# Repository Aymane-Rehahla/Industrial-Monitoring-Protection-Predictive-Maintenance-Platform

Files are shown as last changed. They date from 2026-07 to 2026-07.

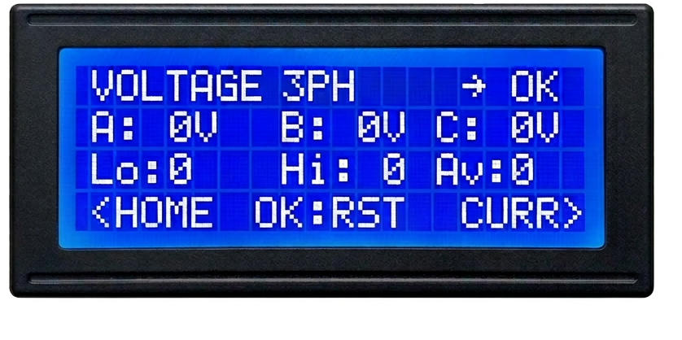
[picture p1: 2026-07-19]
hardware/photos/1775516696009-1775510813756-019d64b0-1b47-77af-adbd-3cf535df64a5.png

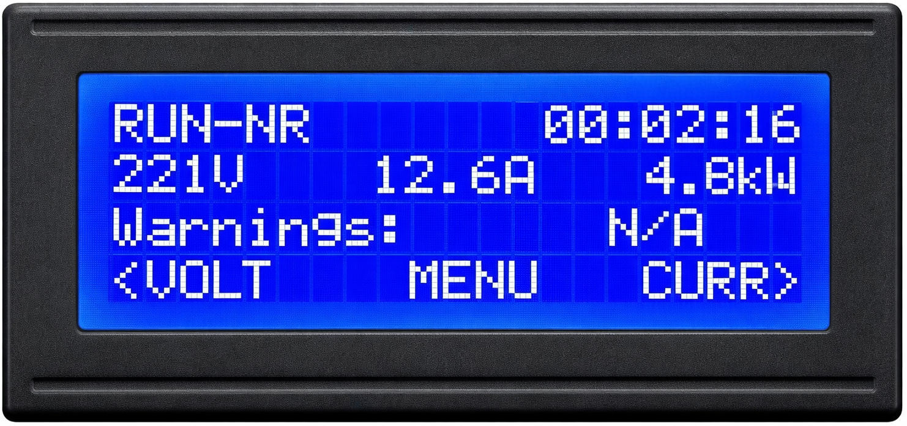
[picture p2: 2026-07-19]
hardware/photos/1775517319582-019d6513-c431-7847-a200-a261fa3e38d0.png

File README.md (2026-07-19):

# Industrial Distributed Monitoring & Protection Platform

> A modular industrial monitoring and protection system built with ESP32-S3 and ESP32 using ESP-IDF.
>
> Designed for reliability, fault tolerance, and safety-critical industrial environments.

---

## Overview

This project is my graduation project and represents the largest embedded system I have designed.

The system monitors industrial electrical and environmental parameters in real time while protecting equipment through a layered safety architecture.

Unlike many academic projects, this system was designed with **industrial reliability** as the primary goal.

It combines:

- Dual ESP32 architecture
- Independent hardware watchdogs
- Redundant communication
- Modular sensor framework
- Industrial HMI
- Remote monitoring dashboard
- Real-time protection algorithms

---

# Architecture

```
                   iPad Dashboard
                  (Web Application)
                         │
                    WiFi / TCP
                         │
                 ESP32 HMI Gateway
                         │
                  Encrypted ESP-NOW
                         │
      ┌──────────────────┴──────────────────┐
      │                                     │
 ESP32-S3 Safety Node A           ESP32-S3 Safety Node B
      │                                     │
      └────────── Cross Validation ─────────┘
                     │
              Dual ATtiny85 Watchdogs
                     │
               Independent NE555 Watchdog
                     │
               Industrial Safety Relay
```

---

# Key Features

## Industrial Protection

- Three-phase voltage monitoring
- Three-phase current monitoring
- Temperature monitoring
- Humidity monitoring
- Gas detection
- RPM monitoring
- Vibration monitoring
- Relay feedback verification
- Fault logging
- Alarm management

---

## Real-Time Processing

The ESP32-S3 performs all protection-critical calculations:

- RMS calculation
- Phase sequence detection
- Phase loss detection
- Voltage imbalance
- Current imbalance
- Frequency measurement
- Locked rotor detection
- Thermal I²t model
- Shock detection
- Safety trips

The ADC hardware provides roughly 860 samples/second in total — not per phase. Reconstructing an accurate current waveform for all three phases at once meant that budget had to be shared rather than used sequentially: the sample rate is divided across the three phases so each one is still captured within the same electrical cycle, instead of measuring one phase fully before moving to the next and introducing timing skew between them.

If a condition can damage equipment...

**the ESP32 reacts immediately.**

---

## Remote Monitoring

The ESP32 Gateway serves a web application accessible from an iPad or any browser.

Features include

- Live dashboard
- Real-time sensor values
- Alarm history
- Historical trends
- Waveform visualization
- Configuration interface
- Maintenance analytics

---

# Safety Philosophy

The most important design goal was **eliminating single points of failure.**

Every protection layer assumes another layer may eventually fail.

## Layer 1 — Software

Industrial state machines

Fault handling

CRC validation

Communication verification

Configuration validation

---

## Layer 2 — Dual ESP32 Supervision

Two ESP32 controllers continuously supervise each other.

Each verifies

- communication integrity
- sensor validity
- heartbeat
- operating state

If disagreement occurs

the system enters a safe state.

---

## Layer 3 — Intelligent Hardware Watchdogs

Two ATtiny85 microcontrollers independently supervise the ESP32 controllers.

Instead of accepting a simple heartbeat,

the watchdog expects a **rolling authentication key**.

This prevents situations where a crashed processor repeatedly outputs the same pulse.

If the rolling key becomes invalid,

the watchdog assumes the firmware is malfunctioning and removes the safety relay.

---

## Layer 4 — Independent NE555 Emergency Watchdog

Even watchdogs can fail.

To eliminate this possibility, an entirely independent NE555 hardware watchdog was added.

Unlike the programmable watchdogs,

the NE555 requires no firmware.

If every controller becomes unresponsive and no valid heartbeat reaches the timer,

the NE555 automatically

- opens the safety contactor
- resets the processors
- forces the system into a safe state

This final layer is completely hardware-based and cannot be affected by firmware bugs.

---

# Contactor State Verification

Commanding the contactor to open is not the same as confirming it actually did.

Under fault current, contactor contacts can weld or stick closed — silently defeating every protection layer above while still reporting a "safe" command was issued.

To catch this, voltage and current are sensed independently on both sides of the contactor: three points upstream (supply side) and three points downstream (load side), one per phase. Comparing the two sides directly reveals the real physical state of the contactor — whether it failed to open when commanded, or is welded shut — rather than relying on the command signal alone.

---

# Modular Sensor Architecture

One design objective was allowing industrial installations to evolve without modifying firmware.

Sensors are treated as independent modules.

Each module can

- be added
- removed
- enabled
- disabled
- configured

independently.

Protection limits are configurable rather than hardcoded.

A hardware switch also selects between simple (3-phase, no neutral) and complex (3-phase + neutral) wiring configurations, so the same platform can be installed across different machine and service types without a firmware change.

This allows the same firmware to support multiple industrial installations with different requirements.

---

# Communication

## ESP-NOW

- encrypted transport
- CRC validation
- packet sequencing
- custom protocol
- low latency

---

## Gateway

The ESP32 gateway converts embedded telemetry into data suitable for the web dashboard.

---

# Technologies

- ESP-IDF
- C
- FreeRTOS
- ESP32-S3
- ESP32
- ESP-NOW
- TCP/IP
- HTML
- JavaScript
- I2C
- UART
- SPI
- ADS1115
- SHT45
- ATtiny85

---

# Project Highlights

✔ Custom communication protocol

✔ Distributed embedded architecture

✔ Modular driver framework

✔ Industrial HMI

✔ Browser-based dashboard

✔ Hardware redundancy

✔ Layered watchdog system

✔ Safety relay verification

✔ Real-time monitoring

✔ Fault logging

✔ Configurable protection system

---

# Current Status

The platform is fully operational and demonstrates

- embedded firmware
- hardware integration
- communication
- industrial HMI
- remote monitoring

Some advanced algorithms are still under active development as the project continues to evolve.

---

# Future Work

- Advanced predictive diagnostics
- PLC integration (Modbus TCP)
- CAN Bus support
- MQTT gateway
- Cloud analytics
- Machine learning maintenance assistant

---

# About Me

I'm an Industrial Electronics Engineer from Algeria passionate about

- Embedded Systems
- Firmware Development
- Industrial Automation
- Safety-Critical Software

I'm currently seeking Embedded Software, Firmware, Electronics and Industrial Automation opportunities with visa sponsorship.

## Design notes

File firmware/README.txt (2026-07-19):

Industrial Monitoring and Protection System

This folder contains the complete project resources including:
- Embedded system code (ESP32-S3)
- Monitoring application
- Documentation

Project Status:
The project is currently in the final optimization and testing phase.
All files will be uploaded in the coming days. (Before 13-4-2026)

Author:
Aymane Rehahla

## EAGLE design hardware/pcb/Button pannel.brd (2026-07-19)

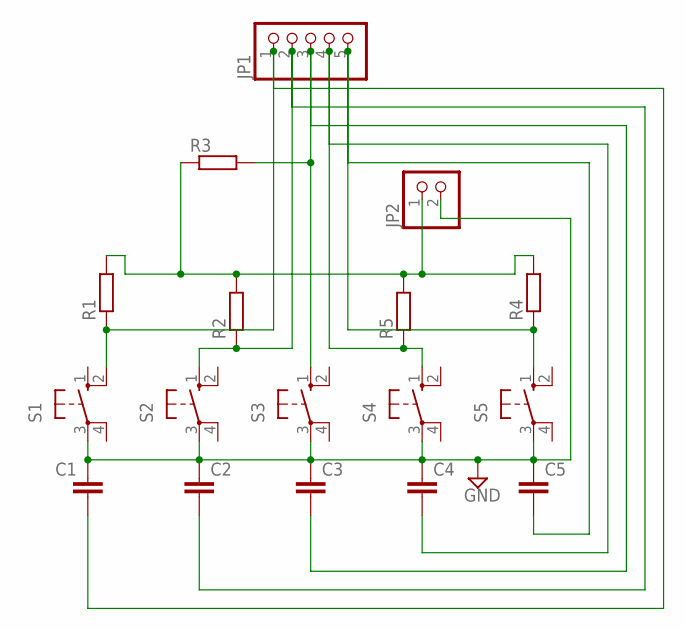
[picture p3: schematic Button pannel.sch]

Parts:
C1, C2, C3, C4, C5: C-EU025-025X050; C025-025X050
JP1: PINHD-1X5; 1X05
JP2: PINHD-1X2; 1X02
R1, R2, R3, R4, R5: R-EU_0204/7; 0204/7
S1, S2, S3, S4, S5: 40-XX; B3F-40XX

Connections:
GND: C1.1, C2.1, C3.1, C4.1, C5.1, JP2.2, S1.3, S2.3, S3.3, S4.3, S5.3
unnamed: C2.2, JP1.2, R2.1, S2.1 (S)
unnamed: C1.2, JP1.1, R1.1, S1.2 (S1)
unnamed: C3.2, JP1.3, R3.2, S3.1 (S)
unnamed: C4.2, JP1.4, R5.1, S4.1 (S)
unnamed: C5.2, JP1.5, R4.1, S5.1 (S)
unnamed: JP2.1, R1.2, R2.2, R3.1, R4.2, R5.2

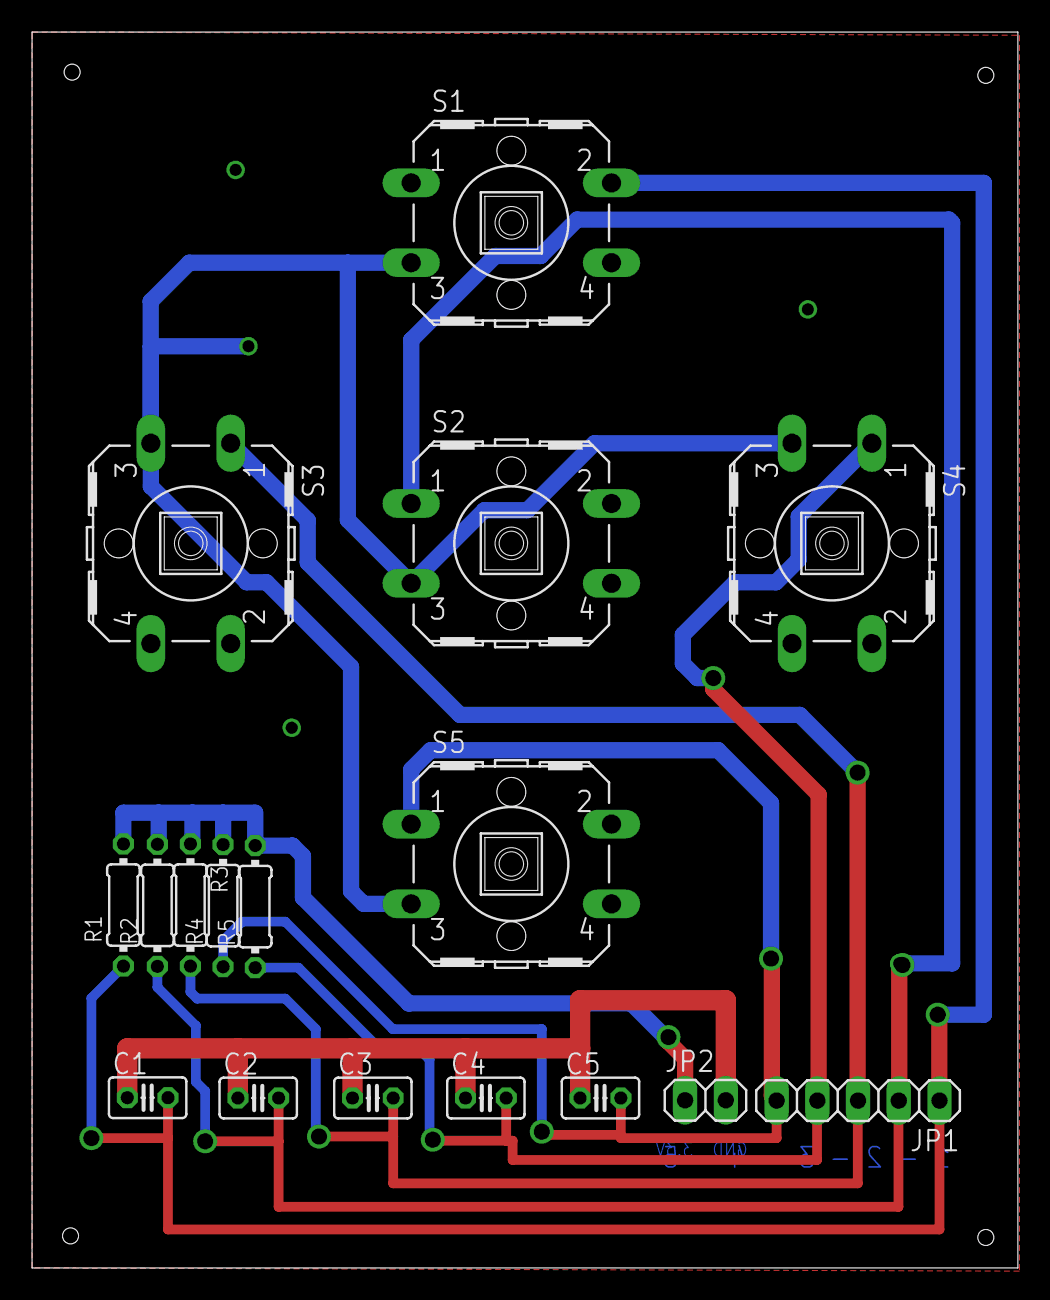
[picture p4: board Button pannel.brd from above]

Board: 2 copper layers, 61.5 x 77.1 mm, 17 parts (0 on the bottom side), 7 nets.

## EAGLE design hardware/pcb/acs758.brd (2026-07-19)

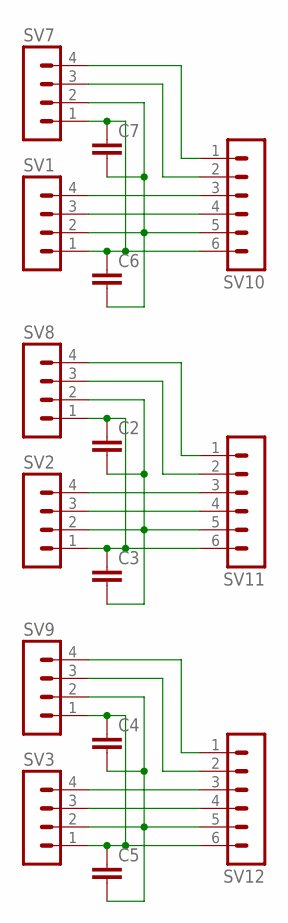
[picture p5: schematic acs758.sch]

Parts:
C2, C3, C4, C5, C6, C7: C-EU025-025X050; C025-025X050
SV1, SV2, SV3, SV7, SV8, SV9: MA04-1
SV10, SV11, SV12: MA06-1

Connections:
unnamed: SV1.3, SV10.4
unnamed: C4.1, C5.1, SV3.1, SV9.1, SV12.6
unnamed: SV2.3, SV11.4
unnamed: SV3.3, SV12.4
unnamed: SV3.4, SV12.3
unnamed: SV9.3, SV12.2
unnamed: SV9.4, SV12.1
unnamed: C2.1, C3.1, SV2.1, SV8.1, SV11.6
unnamed: SV2.4, SV11.3
unnamed: SV8.3, SV11.2
unnamed: SV8.4, SV11.1
unnamed: C6.1, C7.1, SV1.1, SV7.1, SV10.6
unnamed: SV1.4, SV10.3
unnamed: C6.2, C7.2, SV1.2, SV7.2, SV10.5
unnamed: C2.2, C3.2, SV2.2, SV8.2, SV11.5
unnamed: SV7.3, SV10.2
unnamed: SV7.4, SV10.1
unnamed: C4.2, C5.2, SV3.2, SV9.2, SV12.5

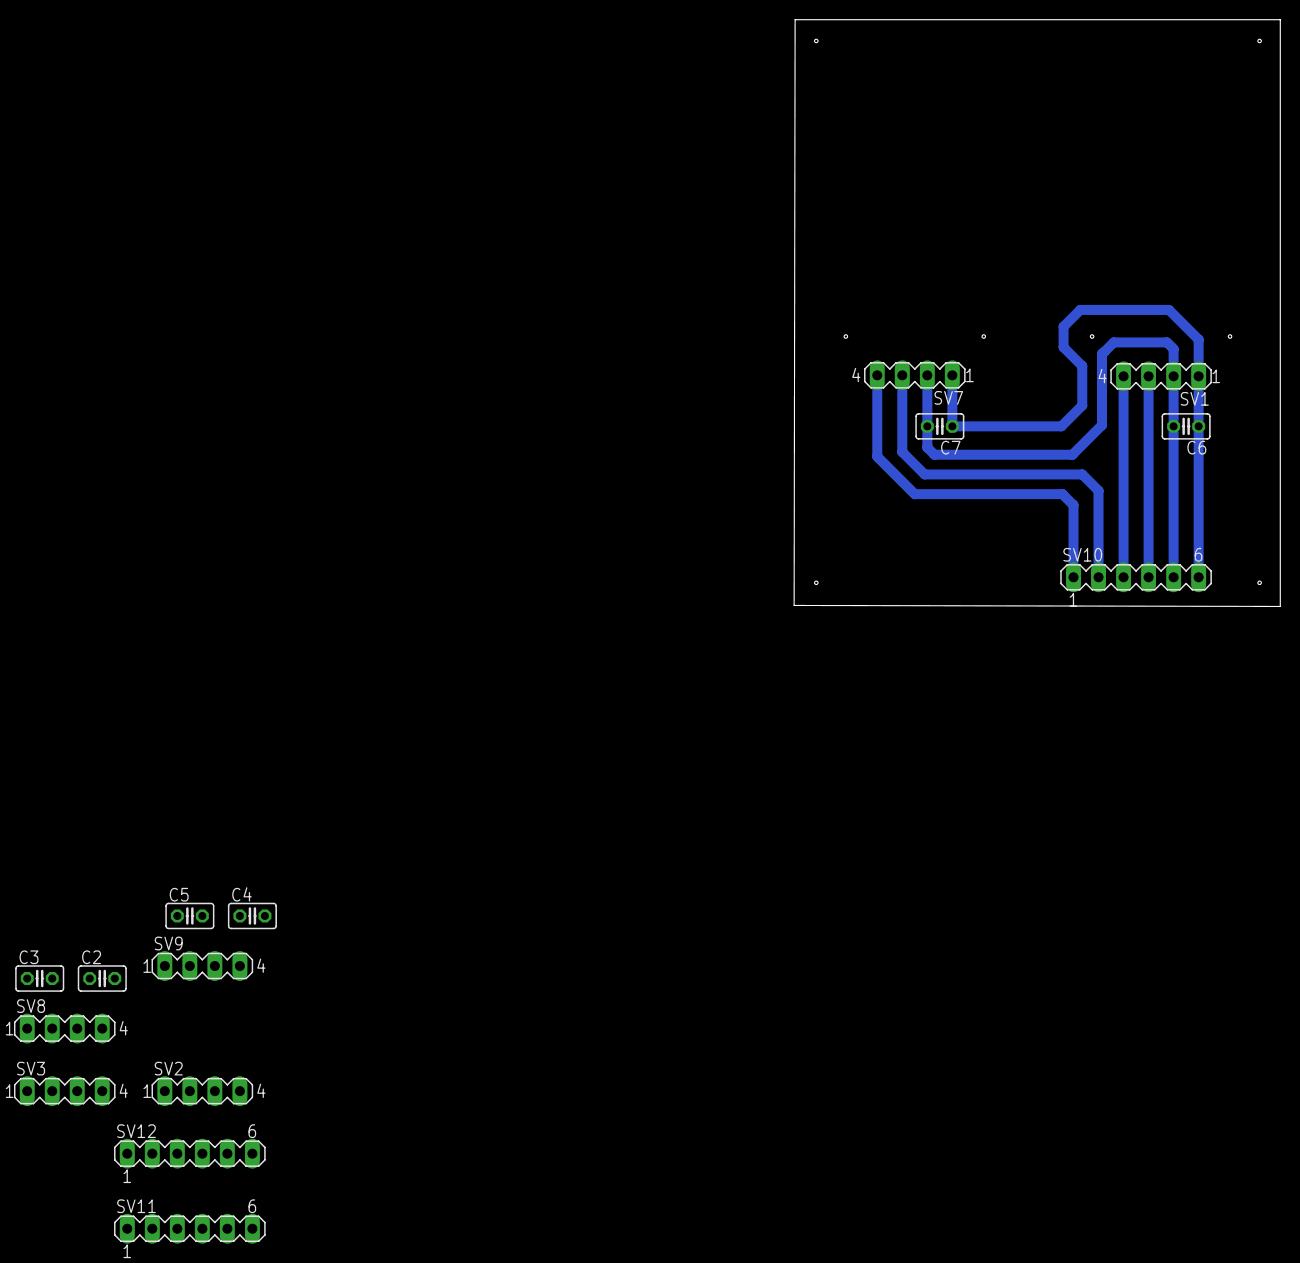
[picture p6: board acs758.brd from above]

Board: 2 copper layers, 49.3 x 59.6 mm, 15 parts (0 on the bottom side), 18 nets.

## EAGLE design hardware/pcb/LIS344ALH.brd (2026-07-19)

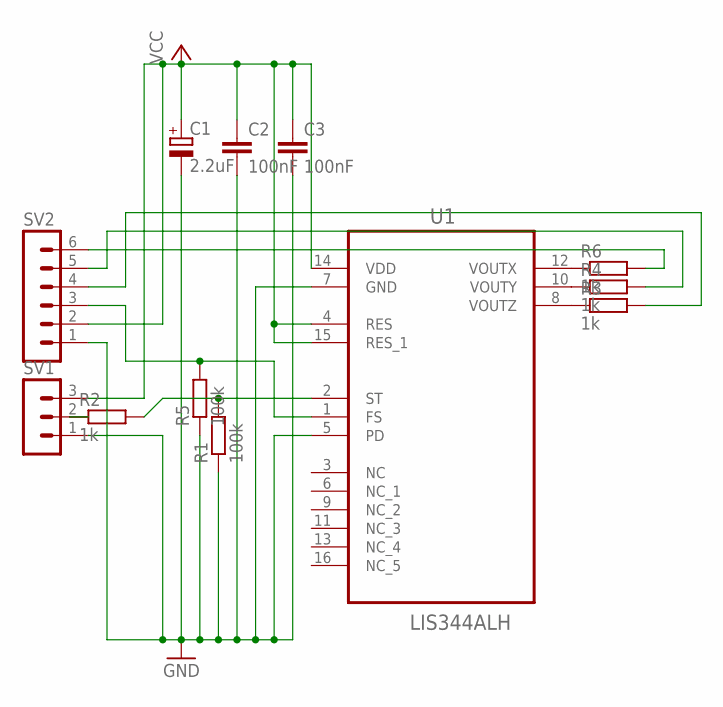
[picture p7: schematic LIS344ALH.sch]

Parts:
C1: 2.2uF; E2,5-6E
C2, C3: 100nF; C2.5-2
R1, R5: 100k; 0204/7
R2, R3, R4, R6: 1k; 0204/7
SV1: MA03-1
SV2: MA06-1
U1: LIS344ALH; LGA16R65P4X4_400X400X160

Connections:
GND: C1.-, C2.2, C3.2, R1.1, R5.1, SV1.1, SV2.1, U1.5 (PD), U1.7 (GND)
unnamed: R6.1, U1.12 (VOUTX)
unnamed: R4.1, U1.10 (VOUTY)
unnamed: R3.1, U1.8 (VOUTZ)
unnamed: R6.2, SV2.6
unnamed: R4.2, SV2.5
unnamed: R3.2, SV2.4
unnamed: R2.1, SV1.2
unnamed: R1.2, R2.2, U1.2 (ST)
unnamed: R5.2, SV2.3, U1.1 (FS)
VCC: C1.+, C2.1, C3.1, SV1.3, SV2.2, U1.4 (RES), U1.14 (VDD), U1.15 (RES_1)

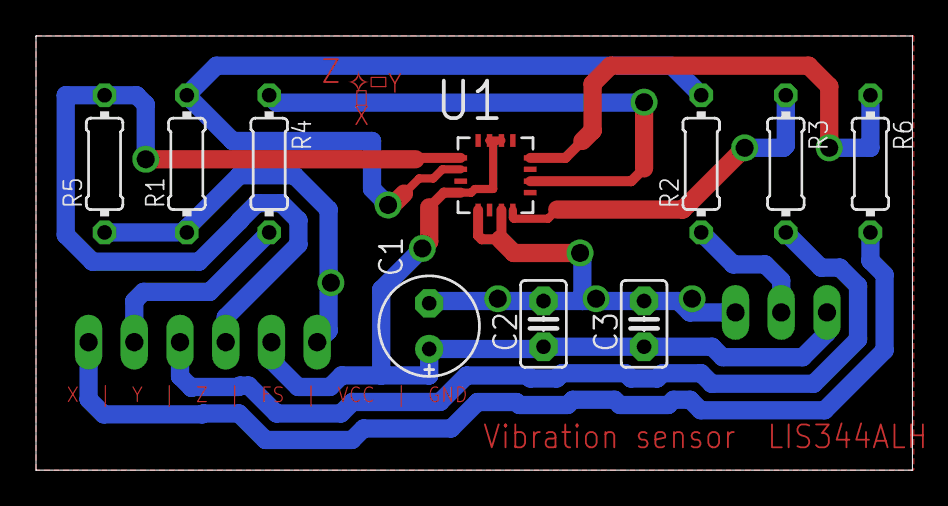
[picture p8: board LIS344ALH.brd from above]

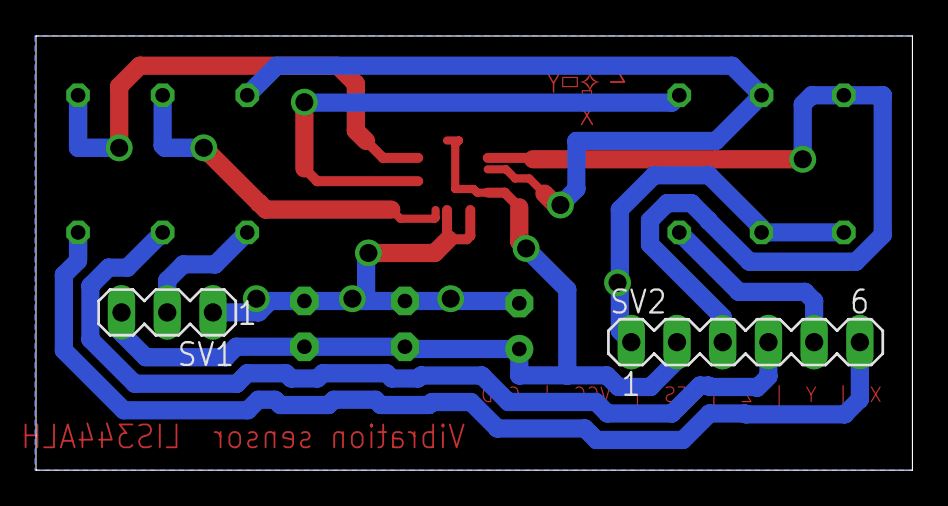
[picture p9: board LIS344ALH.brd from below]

Board: 2 copper layers, 48.7 x 24.1 mm, 12 parts (2 on the bottom side), 11 nets.

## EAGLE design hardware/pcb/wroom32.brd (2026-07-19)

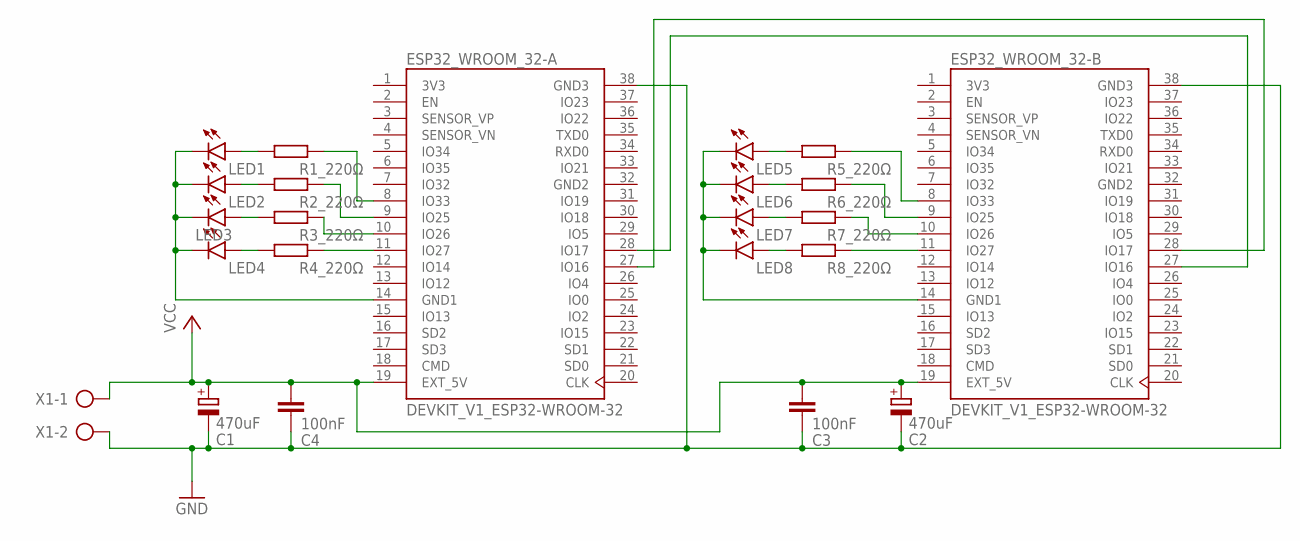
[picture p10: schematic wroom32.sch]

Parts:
C1, C2: 470uF; E2,5-7
C3, C4: 100nF; C025-024X044
ESP32_WROOM_32-A, ESP32_WROOM_32-B: DEVKIT_V1_ESP32-WROOM-32; MODULE_DEVKIT_V1_ESP32-WROOM-32
LED1, LED2, LED3, LED4, LED5, LED6, LED7, LED8: TLLG4400; LED3MM
R1_220Ω, R2_220Ω, R3_220Ω, R4_220Ω, R5_220Ω, R6_220Ω, R7_220Ω, R8_220Ω: R-EU_0207/10; 0207/10
X1: AK500/2-H

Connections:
3V3: ESP32_WROOM_32-A.1 (3V3), ESP32_WROOM_32-B.1 (3V3)
GND: C1.-, C2.-, C3.2, C4.2, ESP32_WROOM_32-A.38 (GND3), ESP32_WROOM_32-B.38 (GND3), X1.2
GND2: ESP32_WROOM_32-A.32 (GND2), ESP32_WROOM_32-B.32 (GND2)
unnamed: ESP32_WROOM_32-A.28 (IO17), ESP32_WROOM_32-B.27 (IO16)
unnamed: ESP32_WROOM_32-A.27 (IO16), ESP32_WROOM_32-B.28 (IO17)
unnamed: ESP32_WROOM_32-B.14 (GND1), LED5.K (C), LED6.K (C), LED7.K (C), LED8.K (C)
unnamed: ESP32_WROOM_32-A.14 (GND1), LED1.K (C), LED2.K (C), LED3.K (C), LED4.K (C)
unnamed: LED1.A, R1_220Ω.1
unnamed: LED2.A, R2_220Ω.1
unnamed: LED3.A, R3_220Ω.1
unnamed: LED4.A, R4_220Ω.1
unnamed: ESP32_WROOM_32-A.11 (IO27), R4_220Ω.2
unnamed: ESP32_WROOM_32-A.10 (IO26), R3_220Ω.2
unnamed: ESP32_WROOM_32-A.9 (IO25), R2_220Ω.2
unnamed: ESP32_WROOM_32-A.8 (IO33), R1_220Ω.2
unnamed: ESP32_WROOM_32-B.8 (IO33), R5_220Ω.2
unnamed: ESP32_WROOM_32-B.9 (IO25), R6_220Ω.2
unnamed: ESP32_WROOM_32-B.10 (IO26), R7_220Ω.2
unnamed: ESP32_WROOM_32-B.11 (IO27), R8_220Ω.2
unnamed: LED8.A, R8_220Ω.1
unnamed: LED7.A, R7_220Ω.1
unnamed: LED6.A, R6_220Ω.1
unnamed: LED5.A, R5_220Ω.1
VCC: C1.+, C2.+, C3.1, C4.1, ESP32_WROOM_32-A.19 (EXT_5V), ESP32_WROOM_32-B.19 (EXT_5V), X1.1

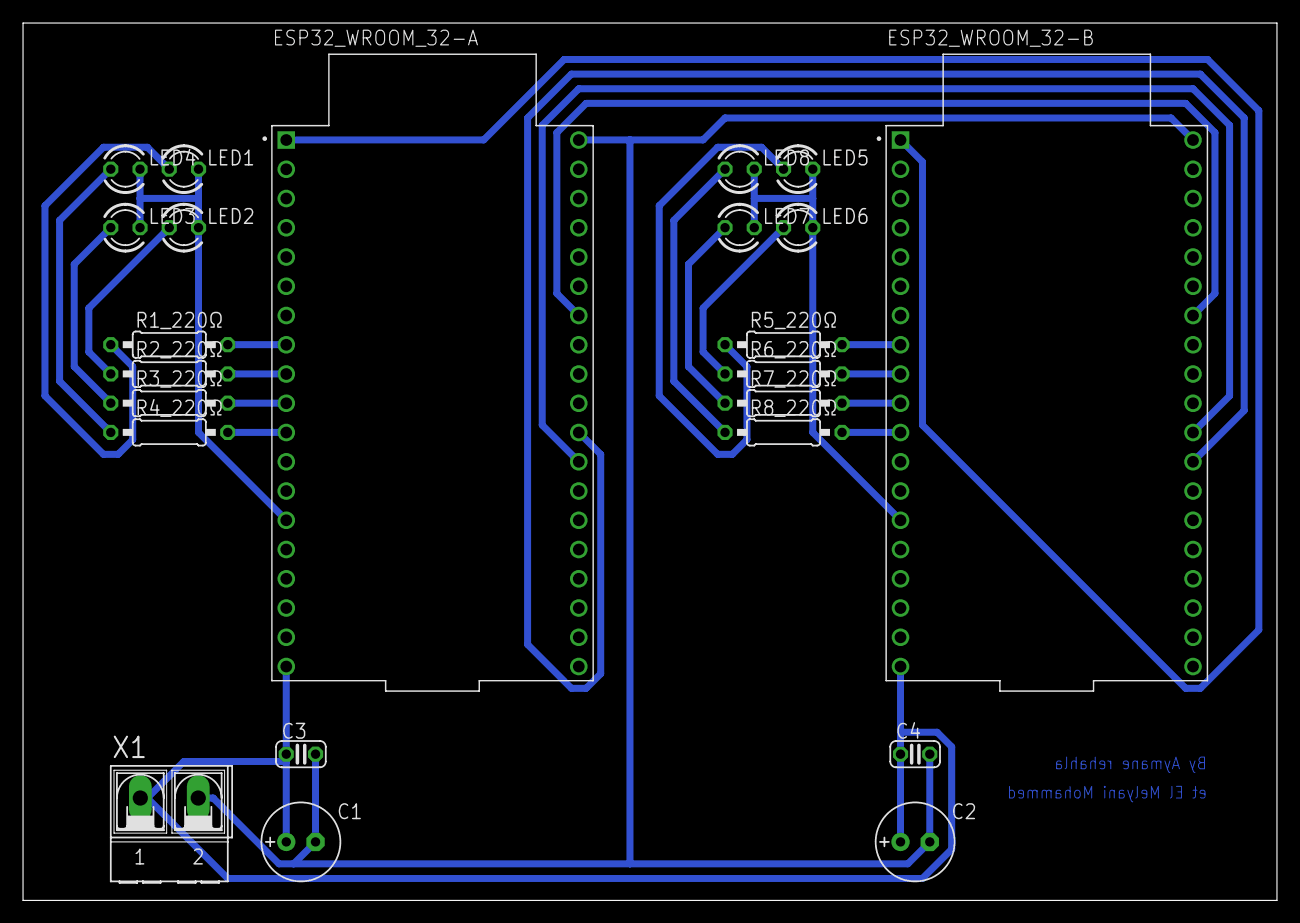
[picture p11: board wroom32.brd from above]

Board: 2 copper layers, 108.9 x 76.2 mm, 23 parts (0 on the bottom side), 24 nets.

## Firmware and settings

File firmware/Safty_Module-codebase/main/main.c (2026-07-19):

/**
 * @file    main.c
 * @brief   Production main — init all subsystems in dependency order.
 * @version 4.0.0
 *
 * CHANGELOG:
 *   4.0.0  2025-01-01  Added comm subsystem init (NVS, ESP-NOW, pairing, telemetry).
 *   3.0.0  2025-01-01  Removed GPIO 5 test task — moved to menu.
 *   2.0.0  2025-01-01  Added GPIO 5 test fault button.
 *   1.1.0  2025-01-01  Removed event-stealing debug loop.
 */

#include "freertos/FreeRTOS.h"
#include "freertos/task.h"
#include "esp_log.h"

#include "system_types.h"
#include "app_config.h"
#include "hal_gpio.h"
#include "hal_i2c.h"
#include "hal_adc.h"
#include "hal_uart.h"
#include "system_status.h"
#include "config_manager.h"
#include "measurement.h"
#include "protection.h"
#include "fault_handler.h"
#include "redundancy.h"
#include "sensor_manager.h"
#include "hmi_manager.h"
#include "drv_lcd2004.h"
#include "drv_buttons.h"
#include "drv_relay.h"
#include "nvs_config.h"
#include "espnow_link.h"
#include "pairing.h"
#include "telemetry.h"

static const char *TAG = "MAIN";

void app_main(void)
{
    error_code_t err;

    ESP_LOGI(TAG, "===== BOOT START =====");
    ESP_LOGI(TAG, "Firmware %s  Built %s %s",
             FIRMWARE_VERSION_STRING, FIRMWARE_BUILD_DATE,
             FIRMWARE_BUILD_TIME);

    /* ── Phase 1: HAL ── */
    hal_gpio_init();
    hal_i2c_init(I2C_BUS_SENSORS);
    hal_i2c_init(I2C_BUS_SHARED);

    err = drv_lcd2004_init();
    ESP_LOGI(TAG, "LCD init: %d  detected=%d", err,
             drv_lcd2004_is_detected());

    err = drv_relay_init();
    ESP_LOGI(TAG, "Relay init: %d", err);

    hal_adc_init();
    hal_uart_init();

    /* ── Phase 2: NVS (must precede WiFi and any NVS consumers) ── */
    err = nvs_config_init();
    ESP_LOGI(TAG, "NVS init: %d", err);

    /* ── Phase 3: Core modules ── */
    system_status_init();
    config_manager_init();
    measurement_init();
    protection_init();
    fault_handler_init();
    redundancy_init();
    sensor_manager_init();

    /* ── Phase 4: Communication (ESP-NOW → pairing → telemetry) ── */
    err = espnow_link_init();
    ESP_LOGI(TAG, "ESP-NOW init: %d", err);

    err = pairing_init();
    ESP_LOGI(TAG, "Pairing init: %d  peers=%u", err,
             pairing_get_peer_count());

    err = telemetry_init();
    ESP_LOGI(TAG, "Telemetry init: %d", err);

    if (err == ERR_OK) {
        telemetry_start();
        ESP_LOGI(TAG, "Telemetry started");
    }

    /* ── Phase 5: HMI (last — everything else must be ready) ── */
    err = hmi_manager_init();
    ESP_LOGI(TAG, "HMI init: %d", err);

    ESP_LOGI(TAG, "===== SYSTEM RUNNING =====");

    /* ── Supervisor loop — watchdog + diagnostics ── */
    while (1) {
        vTaskDelay(pdMS_TO_TICKS(5000));

        telemetry_stats_t tstat;
        telemetry_get_stats(&tstat);

        ESP_LOGI(TAG, "screen=%d role=%d state=%d faults=%lu "
                 "telem_fast=%lu slow=%lu peers=%u",
                 hmi_manager_get_current_screen(),
                 system_status_get_role(),
                 system_status_get_state(),
                 (unsigned long)fault_handler_get_total_count(),
                 (unsigned long)tstat.fast_packets_sent,
                 (unsigned long)tstat.slow_packets_sent,
                 pairing_get_peer_count());
    }
}

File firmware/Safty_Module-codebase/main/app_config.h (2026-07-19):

/**
 * @file    app_config.h
 * @brief   All hardware constants, pin definitions, timing, I2C addresses.
 *          Single point of truth for every configurable value.
 * @version 1.1.0
 * @date    2025-01-01
 * @safety  CRITICAL — Wrong pin or timing constant = damaged equipment.
 *
 * CHANGELOG:
 *   1.1.0  2025-01-01  Fixed duplicate defines, added missing HMI constants.
 *   1.0.0  2025-01-01  Initial release — frozen pin map.
 */

#ifndef APP_CONFIG_H
#define APP_CONFIG_H

#include <stdint.h>
#include <stdbool.h>

/* ═══════════════════════════════════════════════════════════════════════
 *  BOARD / FIRMWARE IDENTIFICATION
 * ═══════════════════════════════════════════════════════════════════════ */
#define FIRMWARE_VERSION_MAJOR   1
#define FIRMWARE_VERSION_MINOR   0
#define FIRMWARE_VERSION_PATCH   0
#define FIRMWARE_VERSION_STRING  "1.0.0"
#define FIRMWARE_BUILD_DATE      __DATE__
#define FIRMWARE_BUILD_TIME      __TIME__
#define BOARD_NAME               "ESP32-S3-N16R8"

/* ═══════════════════════════════════════════════════════════════════════
 *  I2C BUS 0 — SAFETY-CRITICAL SENSORS (ADS1115 x2)
 *  NEVER share this bus with user-facing devices.
 * ═══════════════════════════════════════════════════════════════════════ */
#define PIN_I2C_BUS0_SDA         8
#define PIN_I2C_BUS0_SCL         9
#define I2C_BUS0_FREQ_HZ        400000
#define I2C_BUS0_TIMEOUT_MS      100

/* ═══════════════════════════════════════════════════════════════════════
 *  I2C BUS 1 — SHARED (LCD + SHT45)
 * ═══════════════════════════════════════════════════════════════════════ */
#define PIN_I2C_BUS1_SDA         17
#define PIN_I2C_BUS1_SCL         18
#define I2C_BUS1_FREQ_HZ        100000
#define I2C_BUS1_TIMEOUT_MS      100

/* ═══════════════════════════════════════════════════════════════════════
 *  I2C DEVICE ADDRESSES
 * ═══════════════════════════════════════════════════════════════════════ */
#define I2C_ADDR_ADS1115_VOLTAGE 0x48
#define I2C_ADDR_ADS1115_CURRENT 0x49
#define I2C_ADDR_LCD2004         0x27
#define I2C_ADDR_LCD2004_ALT     0x3F
#define I2C_ADDR_SHT45           0x44

/* ═══════════════════════════════════════════════════════════════════════
 *  I2C SAFETY PARAMETERS
 * ═══════════════════════════════════════════════════════════════════════ */
#define I2C_RETRY_COUNT                  3
#define I2C_BUS_RECOVERY_CLOCK_PULSES   16
#define I2C_ERROR_THRESHOLD             10

/* ═══════════════════════════════════════════════════════════════════════
 *  ANALOG SENSOR PINS (ADC1 ONLY — ADC2 conflicts with WiFi/ESP-NOW)
 * ═══════════════════════════════════════════════════════════════════════ */
#define PIN_ADC_MQ2              1
#define PIN_ADC_MQ4              2
#define PIN_ADC_MQ9              4
#define PIN_ADC_LIS344_X         5
#define PIN_ADC_LIS344_Y         6
#define PIN_ADC_MAX9814          7

/* ═══════════════════════════════════════════════════════════════════════
 *  CD4053BE ANALOG MUX
 * ═══════════════════════════════════════════════════════════════════════ */
#define PIN_MUX_SELECT           3

/* ═══════════════════════════════════════════════════════════════════════
 *  DIGITAL SENSOR PINS
 * ═══════════════════════════════════════════════════════════════════════ */
#define PIN_HALL_RPM            41

/* ═══════════════════════════════════════════════════════════════════════
 *  BUTTON PINS — all active LOW with internal pull-up
 * ═══════════════════════════════════════════════════════════════════════ */
#define PIN_BTN_LEFT            10
#define PIN_BTN_RIGHT           11
#define PIN_BTN_UP              12
#define PIN_BTN_DOWN            21
#define PIN_BTN_OK              42

#define BTN_ACTIVE_LEVEL         0
#define BTN_DEBOUNCE_MS         50
#define BTN_LONG_PRESS_MS     2000
#define BTN_REPEAT_DELAY_MS    500
#define BTN_REPEAT_RATE_MS     150
#define BTN_SCAN_INTERVAL_MS    20      /* How often buttons are polled */

#define APP_BUTTON_COUNT         5

/* ═══════════════════════════════════════════════════════════════════════
 *  BUZZER — PWM via LEDC peripheral
 * ═══════════════════════════════════════════════════════════════════════ */
#define PIN_BUZZER              13

#define BUZZER_LEDC_TIMER        0
#define BUZZER_LEDC_CHANNEL      0
#define BUZZER_LEDC_SPEED_MODE   0
#define BUZZER_LEDC_RESOLUTION  10
#define BUZZER_DUTY_50_PERCENT 512
#define BUZZER_DEFAULT_DUTY    512      /* 50% duty for 10-bit resolution */

/* Tone frequencies (Hz) */
#define TONE_CLICK_HZ         4000
#define TONE_NAV_HZ           2500
#define TONE_CONFIRM_HZ       3000
#define TONE_WARNING_HZ       2000
#define TONE_ERROR_HZ         1000
#define TONE_ALARM_HZ          800
#define TONE_STARTUP_HZ       1500

/* Tone durations (ms) */
#define TONE_CLICK_MS           20
#define TONE_NAV_MS             50
#define TONE_CONFIRM_MS        100
#define TONE_WARNING_MS        200
#define TONE_ERROR_MS          400
#define TONE_ALARM_MS          500
#define TONE_STARTUP_MS        150
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

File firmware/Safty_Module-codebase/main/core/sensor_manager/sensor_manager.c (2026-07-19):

// ═══ FILE: main/core/sensor_manager/sensor_manager.c ═══
/**
 * @file    sensor_manager.c
 * @brief   Sensor manager — STUB implementation with default sensor registry.
 * @version 1.0.0
 * @date    2025-01-01
 * @safety  MEDIUM — Stub only; replace before production.
 *
 * CHANGELOG:
 *   1.0.0  2025-01-01  STUB release.
 */

#include "core/sensor_manager/sensor_manager.h"
#include "app_config.h"

#include "esp_log.h"

#include <string.h>

static const char *TAG = "sensor_manager";

#define NO_GPIO  0xFF
#define NO_I2C   0xFF

/* Justification: Sensor registry must persist across all calls.
 * Modified by add/remove/enable.  File scope. */
static sensor_entry_t s_registry[SENSOR_REGISTRY_MAX];
static uint32_t       s_count       = 0;
static bool           s_initialized = false;

/**
 * @brief  Add one entry to the registry during init.
 *
 * WHY a helper: The default sensor table has 15 entries.  Without
 * this helper, init() would exceed the 50-line limit.
 */
static void reg_add(sensor_type_t type, const char *name,
                    uint8_t gpio, uint8_t bus, uint8_t addr,
                    bool removable)
{
    if (s_count >= SENSOR_REGISTRY_MAX) { return; }

    sensor_entry_t *e = &s_registry[s_count];
    e->type        = type;
    strncpy(e->name, name, SENSOR_NAME_MAX_LEN - 1);
    e->name[SENSOR_NAME_MAX_LEN - 1] = '\0';
    e->gpio_pin    = gpio;
    e->i2c_bus     = bus;
    e->i2c_addr    = addr;
    e->is_enabled  = true;
    e->is_removable = removable;
    e->is_online   = true;  /* STUB: all online */
    s_count++;
}

/* STUB — returns fake data */
error_code_t sensor_manager_init(void)
{
    s_count = 0;

    /* Three-phase voltage via ADS1115 #1 on I2C Bus 0 */
    reg_add(SENSOR_VOLTAGE, "Voltage L1", NO_GPIO, 0, 0x48, false);
    reg_add(SENSOR_VOLTAGE, "Voltage L2", NO_GPIO, 0, 0x48, false);
    reg_add(SENSOR_VOLTAGE, "Voltage L3", NO_GPIO, 0, 0x48, false);

    /* Three-phase current via ADS1115 #2 on I2C Bus 0 */
    reg_add(SENSOR_CURRENT, "Current L1", NO_GPIO, 0, 0x49, false);
    reg_add(SENSOR_CURRENT, "Current L2", NO_GPIO, 0, 0x49, false);
    reg_add(SENSOR_CURRENT, "Current L3", NO_GPIO, 0, 0x49, false);

    /* Environmental sensors on I2C Bus 1 */
    reg_add(SENSOR_TEMP,     "Temperature", NO_GPIO, 1, 0x44, true);
    reg_add(SENSOR_HUMIDITY,  "Humidity",    NO_GPIO, 1, 0x44, true);

    /* Gas sensors via ADC */
    reg_add(SENSOR_GAS_SMOKE,   "MQ-2 Smoke",   1, NO_I2C, 0, true);
    reg_add(SENSOR_GAS_METHANE, "MQ-4 Methane",  2, NO_I2C, 0, true);
    reg_add(SENSOR_GAS_CO,      "MQ-9 CO",       4, NO_I2C, 0, true);

    /* Vibration via ADC */
    reg_add(SENSOR_VIBRATION, "Vibration X", 5, NO_I2C, 0, false);
    reg_add(SENSOR_VIBRATION, "Vibration Y", 6, NO_I2C, 0, false);

    /* Hall-effect RPM */
    reg_add(SENSOR_RPM, "RPM", 41, NO_I2C, 0, false);

    /* Audio level via ADC */
    reg_add(SENSOR_AUDIO, "Audio Level", 7, NO_I2C, 0, false);

    s_initialized = true;
    ESP_LOGW(TAG, "STUB: sensor_manager_init — %lu sensors registered",
             (unsigned long)s_count);
    return ERR_OK;
}

/* STUB — returns fake data */
error_code_t sensor_manager_get_sensor_count(uint32_t *count_out)
{
    if (count_out == NULL) { return ERR_NULL_POINTER; }
    *count_out = s_count;
    return ERR_OK;
}

/* STUB — returns fake data */
error_code_t sensor_manager_get_sensor(uint32_t index,
                                       sensor_entry_t *entry_out)
{
    if (entry_out == NULL) { return ERR_NULL_POINTER; }
    if (index >= s_count)  { return ERR_INVALID_ARG; }

    *entry_out = s_registry[index];
    return ERR_OK;
}

/* STUB — returns fake data */
error_code_t sensor_manager_find_by_type(sensor_type_t type,
                                         sensor_entry_t *entry_out)
{
    if (entry_out == NULL) { return ERR_NULL_POINTER; }

    for (uint32_t i = 0; i < s_count && i < SENSOR_REGISTRY_MAX; i++) {
        if (s_registry[i].type == type) {
            *entry_out = s_registry[i];
            return ERR_OK;
        }
    }
    return ERR_NOT_FOUND;
}

/* STUB — appends to registry */
error_code_t sensor_manager_add_sensor(const sensor_entry_t *entry)
{
    if (entry == NULL) { return ERR_NULL_POINTER; }
    if (s_count >= SENSOR_REGISTRY_MAX) { return ERR_BUFFER_FULL; }

    s_registry[s_count] = *entry;
    s_count++;
    ESP_LOGI(TAG, "STUB: sensor added — %s (total %lu)",
             entry->name, (unsigned long)s_count);
    return ERR_OK;
}

/* STUB — removes from registry */
error_code_t sensor_manager_remove_sensor(uint32_t index)
{
    if (index >= s_count) { return ERR_INVALID_ARG; }
    if (!s_registry[index].is_removable) { return ERR_INVALID_ARG; }

    /* Shift remaining entries down. Bounded by SENSOR_REGISTRY_MAX. */
    for (uint32_t i = index; i < s_count - 1 && i < SENSOR_REGISTRY_MAX - 1; i++) {
        s_registry[i] = s_registry[i + 1];
    }
    s_count--;
    return ERR_OK;
}

/* STUB */
error_code_t sensor_manager_enable_sensor(uint32_t index, bool enable)
{
    if (index >= s_count) { return ERR_INVALID_ARG; }
    s_registry[index].is_enabled = enable;
    return ERR_OK;
}

/* STUB — returns fake data */
bool sensor_manager_is_sensor_online(sensor_type_t type)
{
    for (uint32_t i = 0; i < s_count && i < SENSOR_REGISTRY_MAX; i++) {
        if (s_registry[i].type == type && s_registry[i].is_online) {
            return true;
        }
    }
    return false;
}

const char *sensor_manager_get_type_name(sensor_type_t type)
{
    switch (type) {
        case SENSOR_NONE:        return "None";
        case SENSOR_VOLTAGE:     return "Voltage";
        case SENSOR_CURRENT:     return "Current";
        case SENSOR_TEMP:        return "Temperature";
        case SENSOR_HUMIDITY:    return "Humidity";
        case SENSOR_GAS_SMOKE:   return "Gas (Smoke)";
        case SENSOR_GAS_METHANE: return "Gas (Methane)";
        case SENSOR_GAS_CO:      return "Gas (CO)";
        case SENSOR_VIBRATION:   return "Vibration";
        case SENSOR_RPM:         return "RPM";
        case SENSOR_AUDIO:       return "Audio";
        default:                 return "Unknown";
    }
}
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

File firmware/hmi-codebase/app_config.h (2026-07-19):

/**
 * @file    app_config.h
 * @brief   HMI Gateway configuration — pins, timing, protocol, WiFi.
 *          Single source of truth for all WROOM-32 configurable values.
 * @version 1.0.0
 * @date    2025-01-01
 * @safety  MEDIUM — HMI node, not direct safety path.
 *
 * CHANGELOG:
 *   1.0.0  2025-01-01  Initial release.
 */

#ifndef APP_CONFIG_H
#define APP_CONFIG_H

#include <stdint.h>
#include <stdbool.h>

/* ═══════════════════════════════════════════════════════════════════════
 *  BOARD IDENTIFICATION
 * ═══════════════════════════════════════════════════════════════════════ */
#define FIRMWARE_VERSION_STRING  "1.0.0"
#define FIRMWARE_BUILD_DATE      __DATE__
#define FIRMWARE_BUILD_TIME      __TIME__
#define BOARD_NAME               "ESP32-WROOM-32"

/* ═══════════════════════════════════════════════════════════════════════
 *  DEVICE ROLE — selected via Kconfig menuconfig
 * ═══════════════════════════════════════════════════════════════════════ */
#ifdef CONFIG_WROOM_IS_A
    #define WROOM_ROLE_A         1
    #define WROOM_ROLE_B         0
    #define WROOM_NODE_ID        1
    #define WROOM_NODE_NAME      "HMI-A"
#elif defined(CONFIG_WROOM_IS_B)
    #define WROOM_ROLE_A         0
    #define WROOM_ROLE_B         1
    #define WROOM_NODE_ID        2
    #define WROOM_NODE_NAME      "HMI-B"
#else
    /* Fallback: default to A if Kconfig not used */
    #define WROOM_ROLE_A         1
    #define WROOM_ROLE_B         0
    #define WROOM_NODE_ID        1
    #define WROOM_NODE_NAME      "HMI-A"
#endif

/* ═══════════════════════════════════════════════════════════════════════
 *  LED INDICATOR PINS
 * ═══════════════════════════════════════════════════════════════════════ */
#define PIN_LED_GREEN            4
#define PIN_LED_YELLOW           5
#define PIN_LED_ORANGE          18
#define PIN_LED_RED             19
#define LED_COUNT                4

#define LED_BLINK_SLOW_MS      500
#define LED_BLINK_FAST_MS      150
#define LED_BLINK_HEARTBEAT_MS 1000
#define LED_UPDATE_INTERVAL_MS  50

/* ═══════════════════════════════════════════════════════════════════════
 *  UART2 — WROOM-to-WROOM PEER LINK
 * ═══════════════════════════════════════════════════════════════════════ */
#define PIN_UART_PEER_TX        17
#define PIN_UART_PEER_RX        16
#define UART_PEER_PORT           2
#define UART_PEER_BAUD      115200
#define UART_PEER_RX_BUF       512
#define UART_PEER_TX_BUF       512
#define UART_PEER_SYNC_MS     1000
#define UART_PEER_TIMEOUT_MS  3000

#define UART_PEER_MAGIC        0xA5
#define UART_PEER_MAX_PAYLOAD   200

/* ═══════════════════════════════════════════════════════════════════════
 *  WiFi — APSTA MODE
 * ═══════════════════════════════════════════════════════════════════════ */
#define ESPNOW_WIFI_CHANNEL      1

#if WROOM_ROLE_A
    #define WIFI_AP_SSID         "SAFETY_HMI_A"
#else
    #define WIFI_AP_SSID         "SAFETY_HMI_B"
#endif

#define WIFI_AP_PASSWORD         "safe2025!"
#define WIFI_AP_MAX_CONN         2
#define WIFI_AP_CHANNEL          ESPNOW_WIFI_CHANNEL

/* ═══════════════════════════════════════════════════════════════════════
 *  TCP SERVER
 * ═══════════════════════════════════════════════════════════════════════ */
#define TCP_SERVER_PORT         8080
#define TCP_MAX_CLIENTS            2
#define TCP_RX_BUF_SIZE          256
#define TCP_TX_BUF_SIZE         1024

/* ═══════════════════════════════════════════════════════════════════════
 *  ESP-NOW
 * ═══════════════════════════════════════════════════════════════════════ */
#define ESPNOW_MAX_S3_PEERS      2
#define ESPNOW_RX_QUEUE_SIZE    16
#define ESPNOW_PEER_TIMEOUT_MS 5000

/* ═══════════════════════════════════════════════════════════════════════
 *  COMM PROTOCOL — MUST MATCH S3 FIRMWARE
 * ═══════════════════════════════════════════════════════════════════════ */
#define COMM_PACKET_MAGIC      0x5A
#define COMM_PROTOCOL_VERSION     1
#define COMM_DEVICE_TOKEN  0xC0FEBEEF
#define COMM_AUTH_ROUNDS        32

#define XTEA_KEY_0         0x1A2B3C4D
#define XTEA_KEY_1         0x5E6F7A8B
#define XTEA_KEY_2         0x9C0D1E2F
#define XTEA_KEY_3         0x3A4B5C6D

/* ═══════════════════════════════════════════════════════════════════════
 *  HARDCODED PEER MAC ADDRESSES
 *  Fill in after reading S3 boot logs.
 * ═══════════════════════════════════════════════════════════════════════ */
#define S3_A_MAC    {0x00, 0x00, 0x00, 0x00, 0x00, 0x00}
#define S3_B_MAC    {0x00, 0x00, 0x00, 0x00, 0x00, 0x00}

#if WROOM_ROLE_A
    #define WROOM_PEER_MAC  {0x00, 0x00, 0x00, 0x00, 0x00, 0x00}
#else
    #define WROOM_PEER_MAC  {0x00, 0x00, 0x00, 0x00, 0x00, 0x00}
#endif
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
